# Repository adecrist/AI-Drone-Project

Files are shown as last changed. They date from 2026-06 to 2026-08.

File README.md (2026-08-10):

# Autonomous AI Inspection Drone

## Overview
This repository contains the documentation and milestone planning for a 10-week summer research project developing an AI inspection drone. The system utilizes a Raspberry Pi to process Edge AI vision models in real-time to identify structural defects.

## Current Hardware Architecture
* **Flight Controller/Pixhawk:** Custom implementation using an MPU-6050 Gyro/Accelerometer.
* **Onboard Compute:** Raspberry Pi for Edge AI processing and network telemetry.
* **Power System:** 11.1V (3S) 5000mAh LiPo.
* **Propulsion:** Transitioning to four A2212 1000KV Brushless Motors and matched 12x6E APC propellers (CW/CCW) and 4-30A ESCs
* **Controller/Reciever** FlySky controller/transmitter and FS-iA6B reciever
*  **Camera** ArduCam connected to the raspberry pi through the ribbon

## Repository Contents
* **Week 1 AI Drone Project Presentation:** Slide deck detailing the initial hardware audit, timeline feasibility, and the end goal for the summer
* **Drone Files:** SolidWorks and STL files for the drone parts
* **Drone Project Documentation** Concise description of all of the software and hardware parts from Summer 2025
*  **Wiring Diagram** Brief diagram of how each piece of hardware is connected

## Next Steps
1. Attacth existing hardware to new carbon fiber frame
2. Recallibrate the flight controller on Mission Planner with the new frame
3. Go back to SAS Lab with Prof. Hamid Jafarnejad Sani to test flight

## Live Drone Footage/AI Recognition
1. Connect to the Local Drone Network (PiCam)
2. Verify IP Address by running ipconfig in Windows PowerShell, currently 192.168.4.42
3. In PowerShell type cd "OneDrive\AI Drone Project 2026" ; then python stream.py
4. Connect to Raspberry Pi using ssh terminal
5. Run command: libcamera-vid -t 0 --width 640 --height 480 --framerate 25 --codec h264 --inline --hflip --vflip -o udp://192.168.4.42:5001
6. To shut down press q key on the video feed window and ctrl + c in the raspberry pi terminal

## Connecting to Raspberry Pi
1. Plug in the LiPo battery and connect to PiCam on your laptop
2. Open up command prompt on your computer type in ssh lpan@192.168.4.1 then enter Password Steven27

## Downloading Mission Planner
1. Must have a windows computer
2. Go to the official ArduPilot Mission Planner download directory
3. Click on MissionPlanner-latest.msi for most recent version
4. Go to you downloads to find the file and click it to launch setup wizard
5. Make sure too allow all the pop ups that ask to install device drivers
6. Once installation is complete use the micro-USB cable to connect the Pixhawk to your computer set baud rate to 115200
7. Navigate to Setup then Mandatory Hardware if calibration needs to be done

## Connecting Controller/Transmitter
1. Plug in battery on the drone
2. Hold down the button on the saftey switch(currently have the safety switch turned off), connected to Pixhawk, should hear motor start up sound
3. Turn on the FlySky Transmitter
4. Make sure the throttle is all the way down and the SWA switch if pushed up
5. Bring throttle to the bottom right position until the blue light on the pixhawk is a solid blue
6. Transmitter is then connected
7. To disconnect flick SWA down, then bring throttle to bottom left position until Pixhawk is flashing green

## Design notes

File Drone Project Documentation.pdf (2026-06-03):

Drone Project Documentation

Lawrence Park

## Hardware:

3D Printed Components:

The STL files for each part are available, as well as the .f3d file for the drone overall. The names for each component are mostly self-descriptive, with the one exception being the “Drone Pin 1.0” and “Drone Pin Long 1.0”. The finalized design mainly uses the long pin variant, but the shorter pin can be used at the cost of potential rigidity. Furthermore, the pins holding the arms to the main body can be very difficult to remove and not all the pin slots are through holes. The first camera-side pin slot on both sides of the drone is a blind hole, so caution should be taken when using the pins on those slots. This problem can be worked around by either not fully inserting the pins on the blind holes, or by designing a new pin with more material on the top for easier removal.

Propeller Blades:

The propeller blades used in this project are two-bladed 12 x 6 propellers. The drone currently has two counterclockwise propellers with these dimensions, so the next step would be to purchase two more of these propellers, with care taken to make sure that they are clockwise (the drone requires two counterclockwise propellers and two clockwise propellers to balance out torques for yaw control).

## Electronics:

Battery:

The drone uses a 11.1V, 3S1P, 5000 mAh battery with a XT60 connector. This battery is compatible with the OVONIC battery charger provided.

Electronic Speed Controller (ESC):

Four 30A RCElectricParts electronic speed controllers are used. These are necessary for the controlled operation of each motor. These ESCs have three groups of connections. The XT60 female connector is used to power the ESC from the battery. The DuPont wire connectors are used to control the ESC from the circuit board, with the white wire being data, the black wire being ground, and the red wire being a 5V BEC (not used). Lastly, the three wires with “banana” connectors are used to connect to the motor, with the roles being as follows: the blue wire is the data cable and corresponds to the yellow wire on the motors, and the red and black wires are for power and ground, respectively. These wires can connect to the red and black of the motors, the order of which changes the direction the motor spins (i.e. changing from black-black and red-red to black-red and red-black).

Motor:

Four A2208 / 8T, 2600 KV motors are used. These motors are mounted to the frame using four metric M3 bolts per motor. Each motor is exclusively powered by the ESC and should not be powered by the circuit board. The direction of each motor can be changed by swapping the ground and power cables that connect to the ESC. The drone should have two counterclockwise motors and two clockwise motors, corresponding to the type of propeller that each motor has mounted on it. The propellers are mounted onto the drone by the prop adapter, which should be tightened down thoroughly before use. Do not test the motors with propellers attached unless proper precautions are taken beforehand. It should be noted that the entire external body of the motor spins, not just the spigot.

Universal Battery Eliminator Circuit (UBEC):

The UBEC is used to step down the 11.1V from the battery to 5V/3A that is usable by the Raspberry Pi. This UBEC is connected to a female XT60 connector via heat shrink tubing, so avoid disconnecting the UBEC by pulling on the wires themselves. Instead, try to only pull on the exposed plastic sections of the XT60 connectors.

5-Way Splitter:

The splitter is used to split the battery’s power to five different components. The splitter has one female XT60 connector and five male XT60 connectors. The female connector connects to the battery, and the male connectors connect to the four ESCs and the UBEC.

MPU-6050 6-axis Accelerometer and Gyroscope:

This gyroscopic sensor can be used to detect the orientation of the drone, as well as the acceleration in X, Y, and Z. The MPU-6050 has connectors that must be soldered with the provided adaptor to ensure the reliability of the connection during flight. These connectors should be connected to the Raspberry Pi to allow the readings to be measured. This senor uses metric M2.5 bolts.

PCA-9685 PWM Driver:

The PWM driver is used to control all four motors at the same time. Each motor requires a PWM signal to discern analog speeds, and the Raspberry Pi only has two discreet PWM signals, so the PWM driver is necessary to control all four motors. The PWM board has 16 channels, with three pins used for each channel. The yellow pin is the signal pin which connects to the white wire of the ESC. The black pin is the ground and connects to the black wire of the ESC. Lastly, the red pin is the power pin, which would be used to power the board from the

ESCs, but the PWM driver board is being powered by the Raspberry Pi, so this pin should remain unconnected. This board uses metric M2.5 bolts.

ArduCam V3:

Connects to Raspberry PI via CSI-2 serial port. Has adjustable framerate and video quality. Currently is mounted inverted. Attaches via ~1.5-2M bolts.

Raspberry Pi 4:

The circuit board that controls the function of the drone. More detail on the control can be found in the “Software” section. The Raspberry Pi uses a 64 GB microSD card as memory, and this card is necessary for the operation of the board. If more memory is needed, the microSD card can be changed. The board is powered either by UBEC into pins 4 and 6, or by USB-C. The board can be interfaced with by plugging a monitor into the micro-HDMI port, and a keyboard and mouse into the USB-3 ports.

The board has multiple pinouts of various purpose, including powering and providing inputs for the PCA-9685, as well as reading outputs from the MPU-6050. The Raspberry Pi directly connects to the ArduCam via the data ribbon. Additional account information found below:

Username: lpan

Password: Steven27

IP: 192.168.1.165

## Software:

Raspberry Pi Wi-Fi Hotspot:

The Raspberry Pi can emit a Wi-Fi hotspot under the name of PiCam by running the following line in the Raspberry Pi terminal.

nmcli connection up pi-hotspot

The hotspot can be disabled by running the following line.

nmcli connection down pi-hotspot

Raspberry Pi Wi-Fi Video Streaming:

Using GStreamer, video feed can be streamed over the Raspberry Pi’s hotspot to a receiving computer (must be connected to the hotspot). The stream can be started with the following line:

Libcamera-vid -t 0 --width 640 --height --framerate 25 --
codech264 --inline --listen -o - | gst-launch-1.0 -v fdsrc !

h264parse ! rtph264pay config-interval=1 pt=96 ! udpsink host=192.168.4.66 port=5000

## Recommended First Steps:

Hardware:

- Purchase proper sized and orientation propeller blades
- Design attachment for MPU-6050

Electronics:

- Connect MPU-6050 to proper pins

Software:

- Digitally flip video camera feed
- Get readings from MPU-6050
- Run basic flight test to ensure weights and power is appropriate

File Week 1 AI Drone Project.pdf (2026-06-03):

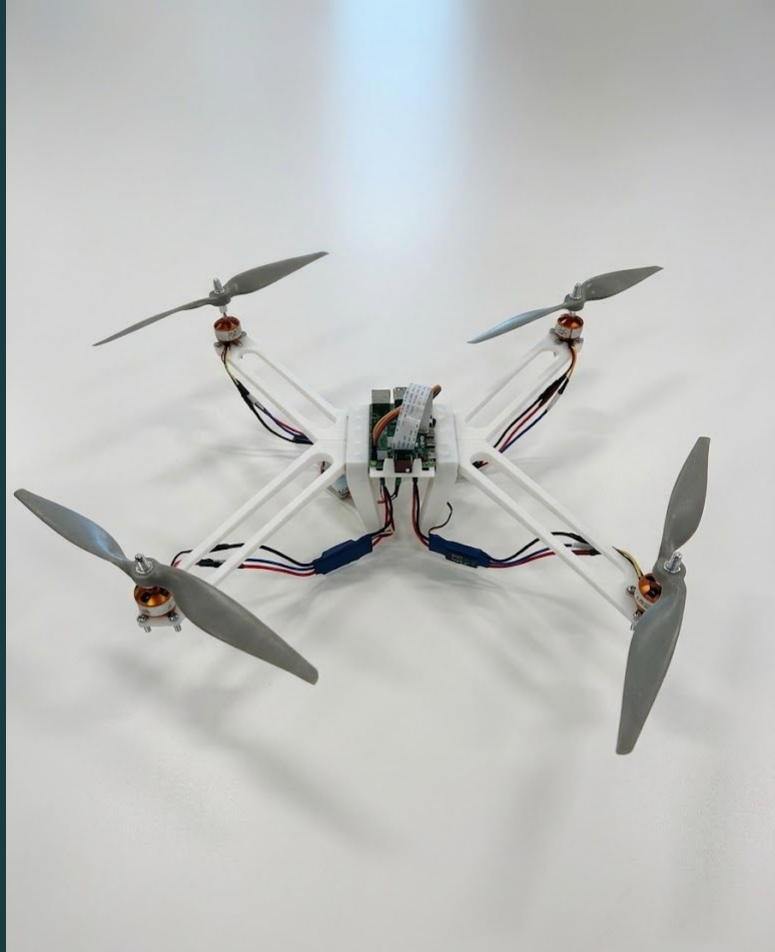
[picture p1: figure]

# AI Drone Project

Adam DeCristofaro
6/1/26

# Content overview

## Industry Standard

- Traditionally serve as flying cameras
- More recently AI has been applied to after flight

## Project Goal

- Create a drone “coworker” who you can communicate with in real time

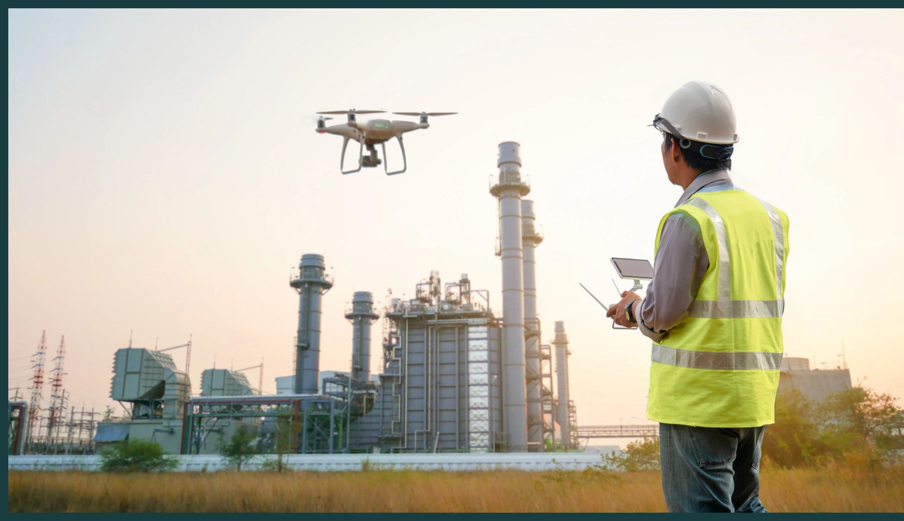
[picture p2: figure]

# Day 1 Hardware Audit

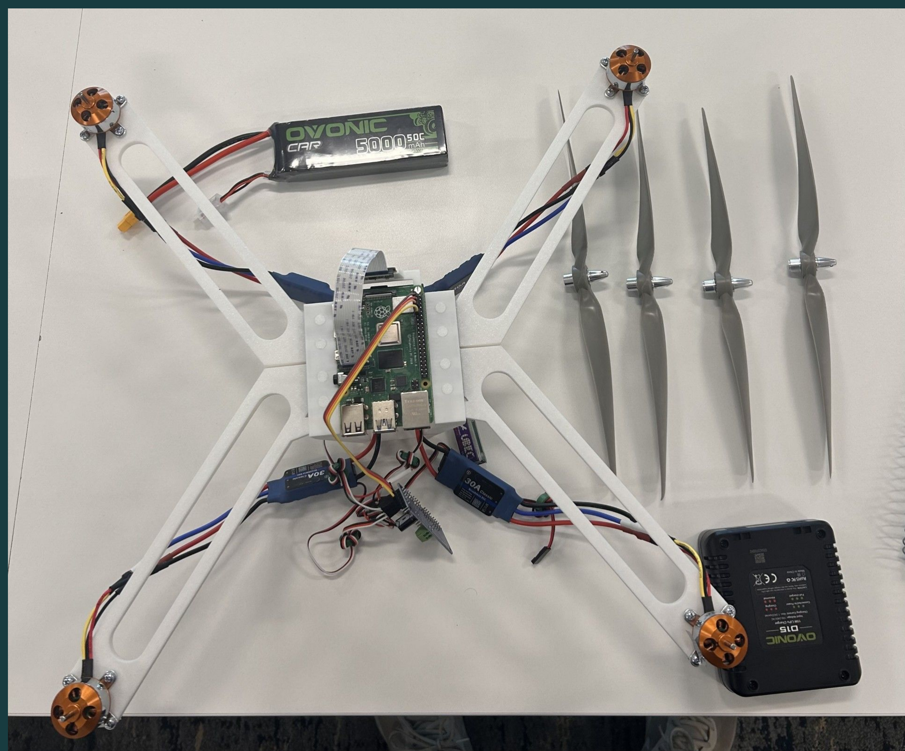
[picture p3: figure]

- All of the parts in the report from last summer are accounted for
- | MPU-6050 Gyroscope is currently unmounted ● | Drone currently has counterclockwise blades and needs

two clockwise blades for yaw balance

- Current blades are too long for the motors size(2600kV)

# Day 1 Software

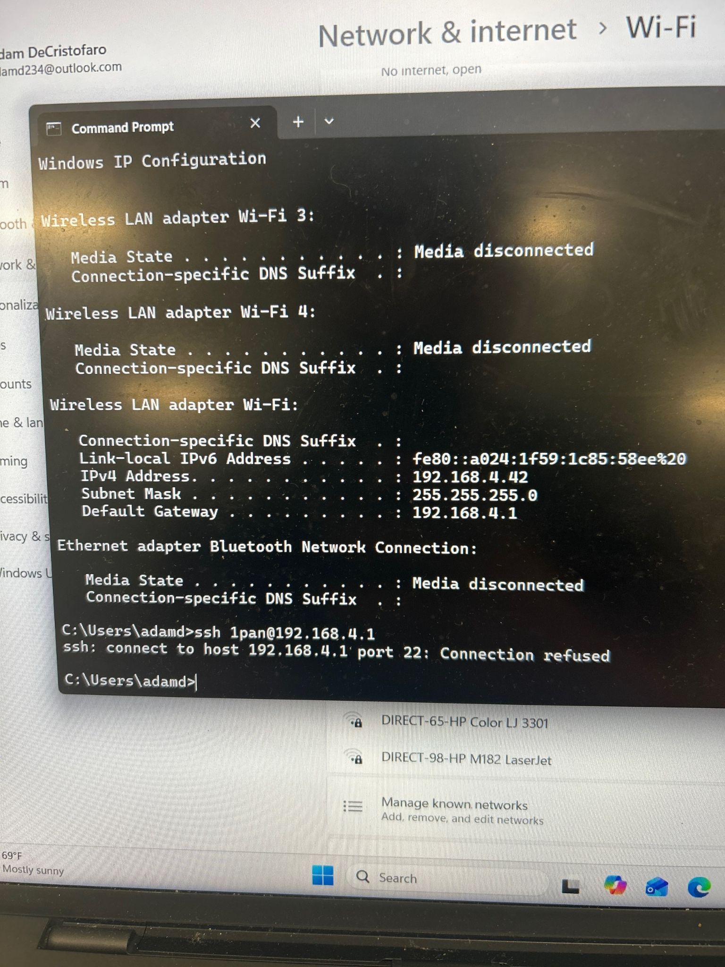
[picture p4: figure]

# Audit

- | Successfully connected to the Raspberry Pi WiFi “PiCam” ● | Was unable to connect wirelessly as the ssh port was refusing

connections

- Plan to access it locally using a monitor to flip the ssh allowing wireless connections

# Next Steps

## Summer Outline

- Order different blades or motors
- Create an attachment for the gyroscope
- Connect to the raspberry pi to get live footage from the camera
- Test the drone for flight
- Begin developing the AI models for real time detection

## Goals for Next Week

- Order the correct blades
- Connect to raspberry pi

Weeks 7-10 | End Goal for the Summer
| Be able to manually drive the drone inside of Debaun gym and have it detect staged “defects” in the walls and communicate it back to the user
Install AI models into the
drones software so it can
detect defects like a crack in a wall or window and
send a message back to the user in real time

Achieve flight with the
drone with programmed
flight and the use of a
controller
2. Weeks 3-6

Successfully equip the
drone with all of the parts necessary for flight
1. Weeks 1 & 2

## Milestones

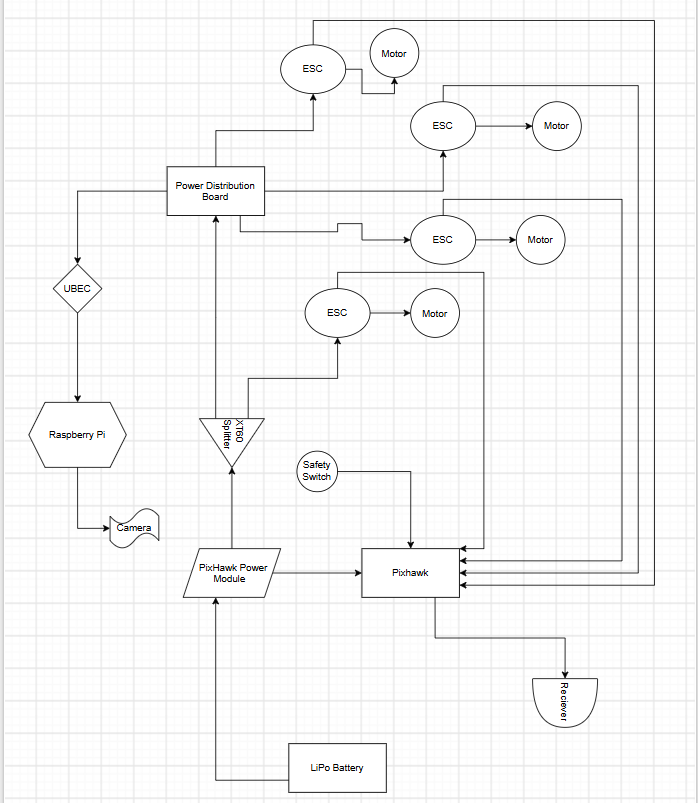
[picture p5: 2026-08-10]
Screenshot 2026-07-27 143617.png

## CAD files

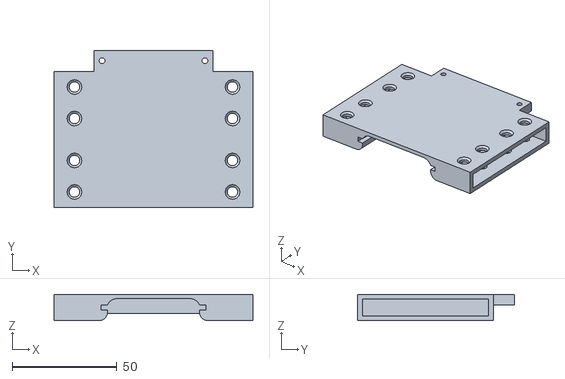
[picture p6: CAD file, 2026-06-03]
AI Drone Project 2026/Drone Files/Drone Main Body 3.0.stl
94.8 x 75.0 x 12.5

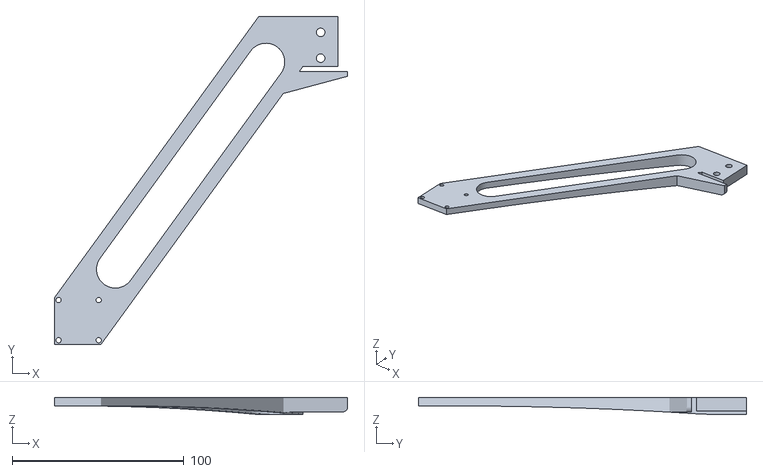
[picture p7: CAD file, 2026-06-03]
AI Drone Project 2026/Drone Files/Drone Rear Left 1.0.stl
170.7 x 190.8 x 10.0

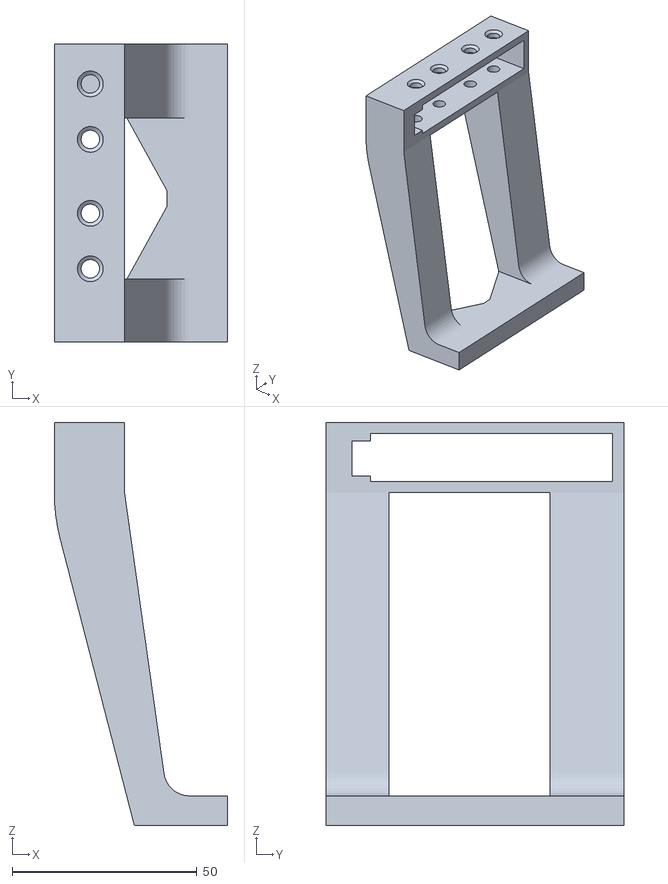
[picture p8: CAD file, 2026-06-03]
AI Drone Project 2026/Drone Files/Drone Battery Holder Left 1.0.stl
46.9 x 80.5 x 109.0

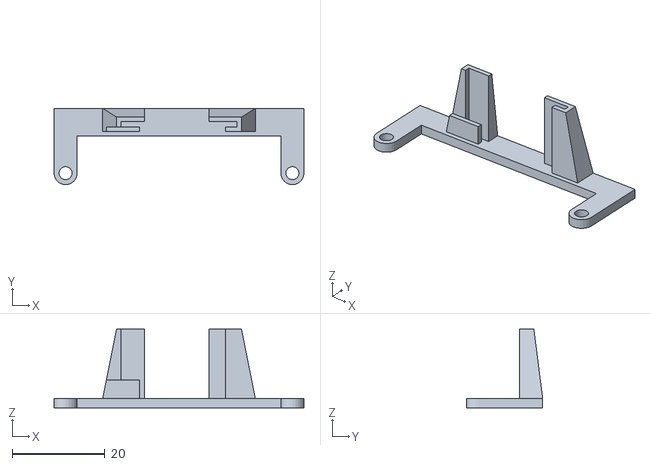
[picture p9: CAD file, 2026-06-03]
AI Drone Project 2026/Drone Files/Drone Camera Holder 1.0.stl
54.0 x 16.5 x 17.0

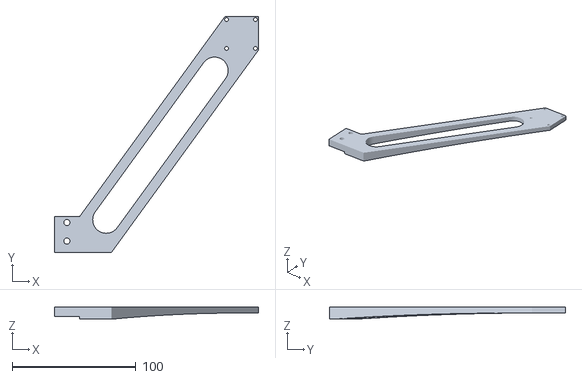
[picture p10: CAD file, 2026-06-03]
AI Drone Project 2026/Drone Files/Drone Front Right 1.0.stl
164.9 x 190.8 x 10.0

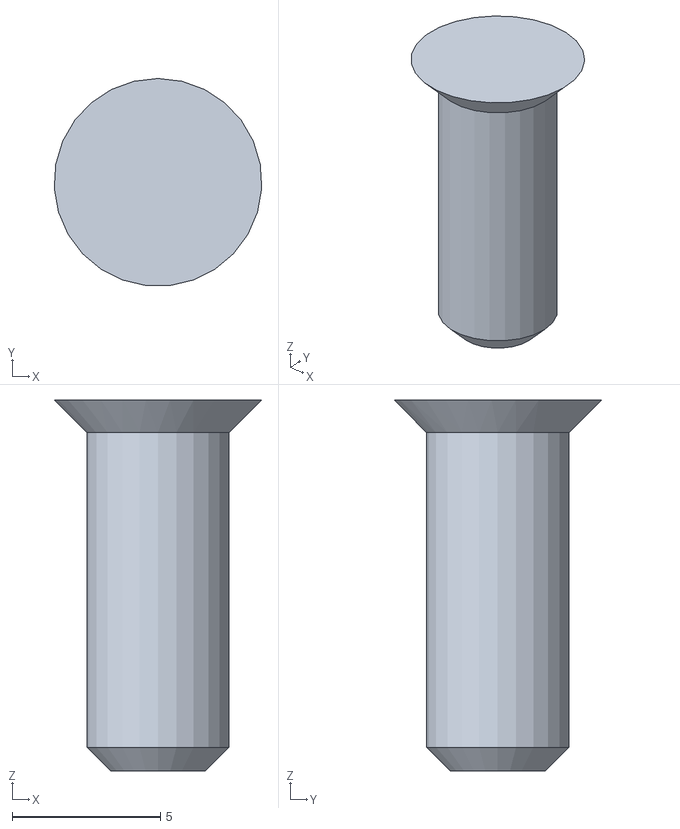
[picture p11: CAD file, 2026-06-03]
AI Drone Project 2026/Drone Files/Drone Pin 1.0.stl
6.99 x 6.98 x 12.5

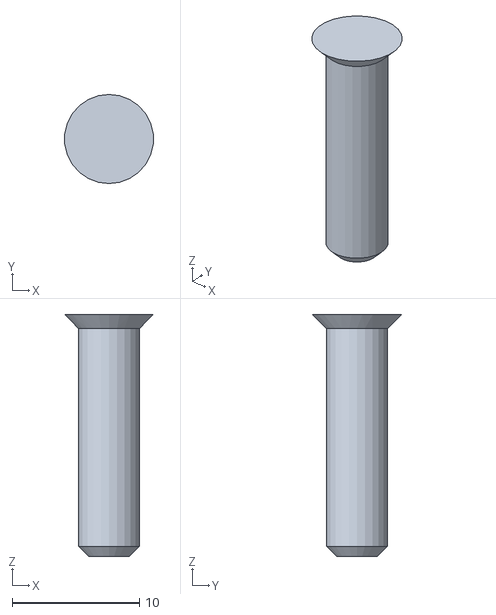
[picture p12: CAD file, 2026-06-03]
AI Drone Project 2026/Drone Files/Drone Pin Long 1.0.stl
6.95 x 7.00 x 19.0

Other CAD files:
AI Drone Project 2026/Drone Files/Drone Battery Holder Right 1.0.stl
AI Drone Project 2026/Drone Files/Drone Front Left 1.0.stl
AI Drone Project 2026/Drone Files/Drone Rear Right 1.0.stl
AI Drone Project 2026/Drone Files/Drone Frame.f3d

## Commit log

2026-08-10 Rename Screenshot 2026-07-27 143617.png to Wiring Diagram
2026-08-10 Add files via upload
    Wiring Diagram
